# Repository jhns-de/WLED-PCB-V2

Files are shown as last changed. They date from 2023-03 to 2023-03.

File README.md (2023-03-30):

# WLED PCB V2

This is an ESP8266 based controller to drive addressable 12V [GS8208](www.normandled.com/upload/201805/GS8208%20LED%20Datasheet.pdf) LED Strips with the amazing [WLED](https://github.com/Aircoookie/WLED) firmware.

**This PCB was designed in [KiCad](https://www.kicad.org/).**

## Features

- Dimensions 95mm x 40mm
- Onboard LED for testing
- Fuse for overcurrent protection
- Reverse polarity protection for input and output
- [Recommended](https://kno.wled.ge/basics/compatible-hardware/#levelshifters) SN74AHCT125N Levelshifter
- Multiple decoupling capacitors
- IR receiver
- Relay for completely switching of the LED Stripe
- INA219 power sensor
- Multiple test points
- Onboard LED Stripe extension adapter

## Goal

This PCB was designed as an LED Stripe controller board for digital 12V GS8208 LED Strips built into a shelf. Therefore, it had to be easy to connect the LED Strips on either side of the board (depending if the board is mounted on the left or right side of the shelf). In addition, the LED Stripe hat to be easy extendable over the board, so the LED Stripe doesn't end before the shelf ends.

## More Information

Due to the backup line of the GS8208 LED design it is possible to completely remove the test led or the onboard led stripe extension adapter.

## Warning

In my first revision I connected the INA219 improperly. Therefore, I was unable to use it and never got to actually implementing the sensor into WLED. I updated the schematics and board to connect the INA219 sensor properly, but better check twice.

## WLED PCB V2

### Schematic

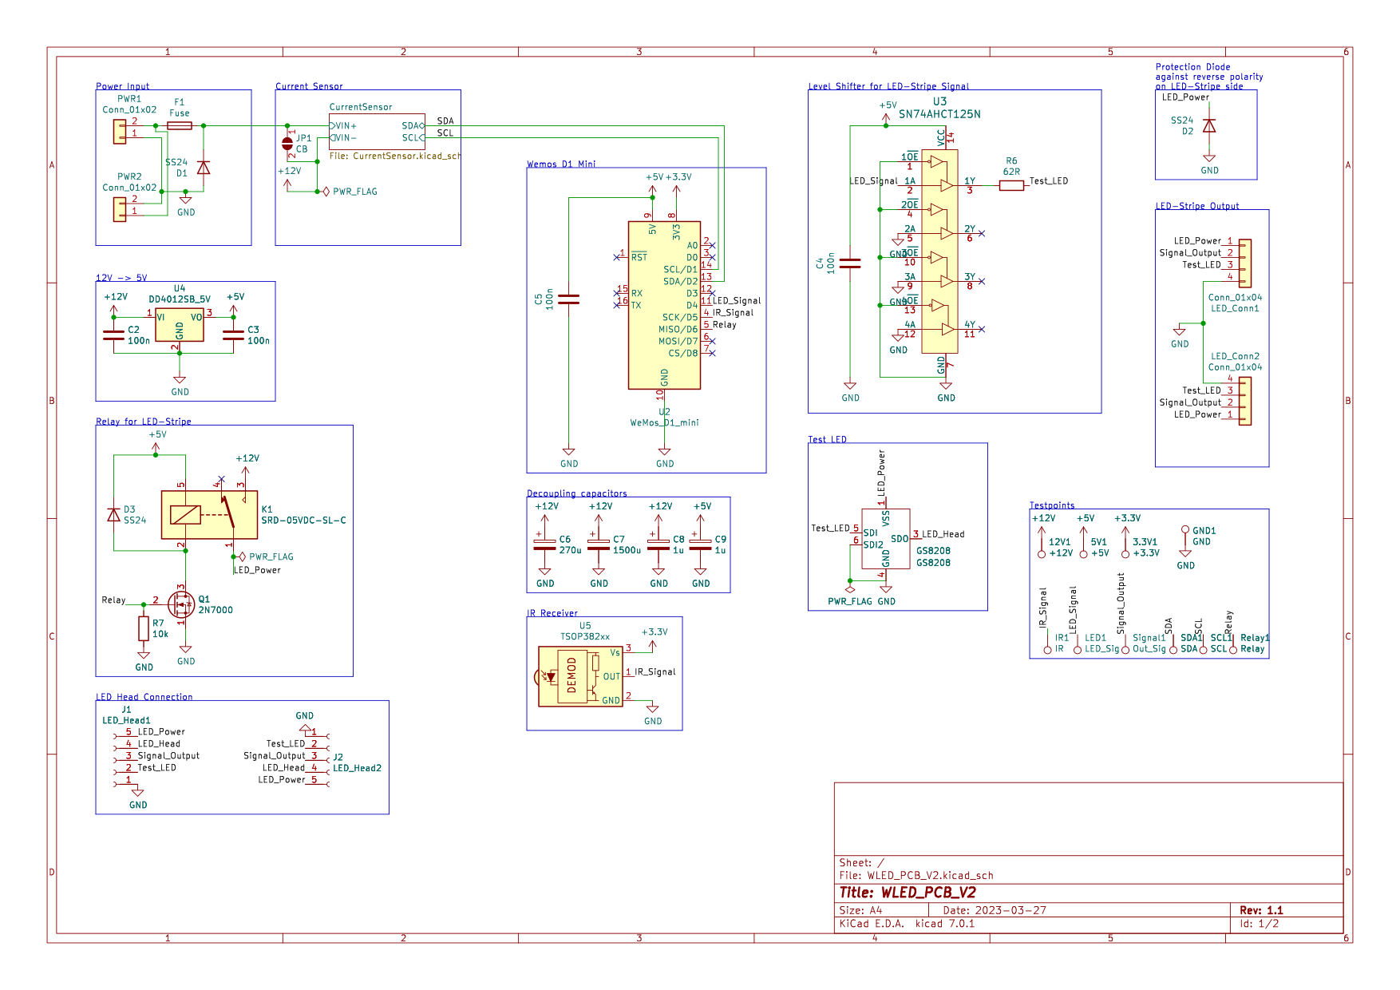
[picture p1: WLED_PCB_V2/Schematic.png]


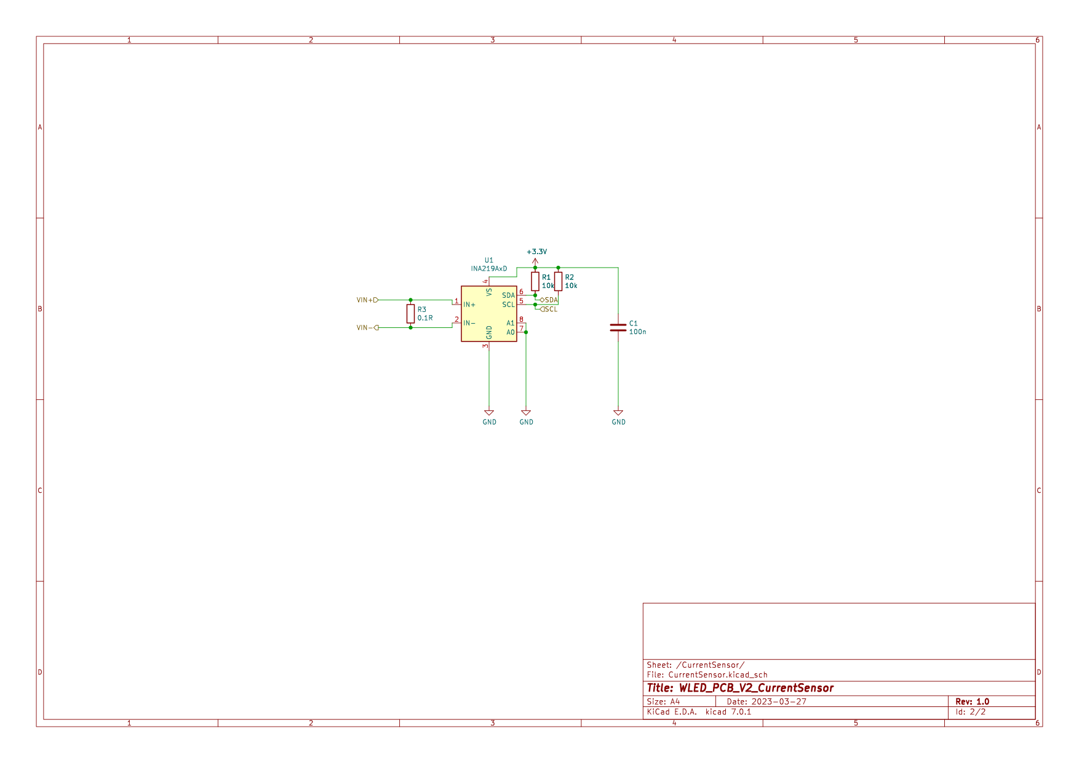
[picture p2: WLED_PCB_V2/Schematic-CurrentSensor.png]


### PCB

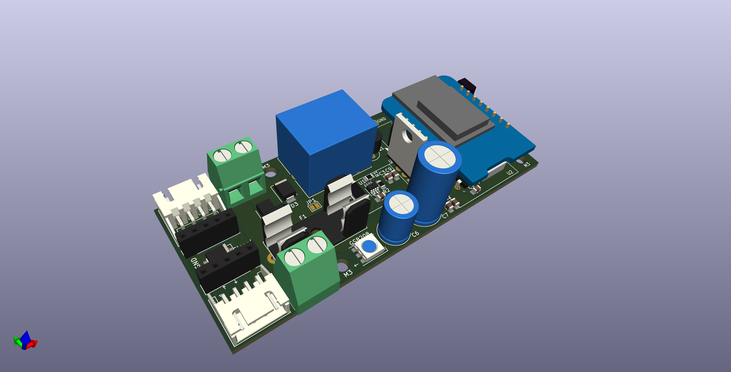
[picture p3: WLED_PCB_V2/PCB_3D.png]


#### Front

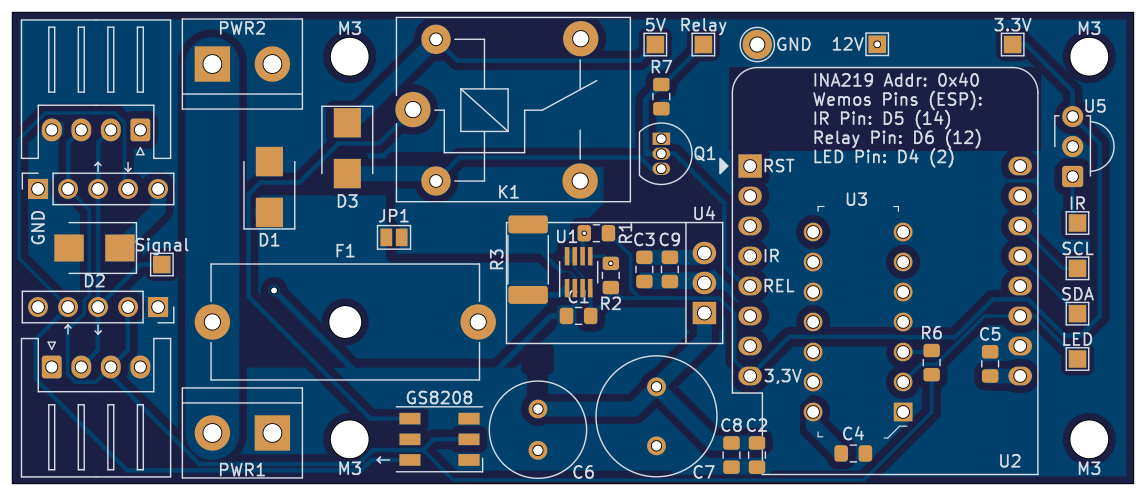
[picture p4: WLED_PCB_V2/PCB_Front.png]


#### Back

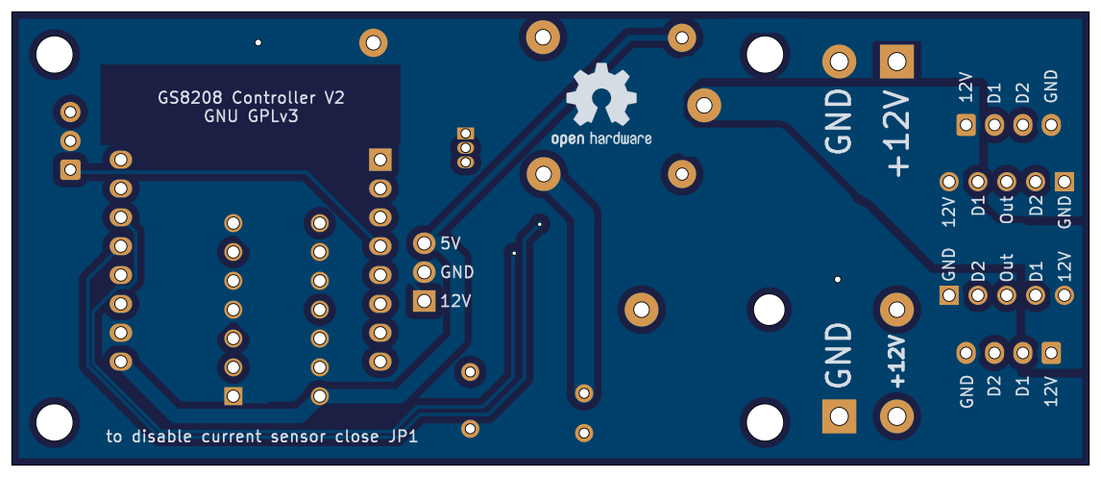
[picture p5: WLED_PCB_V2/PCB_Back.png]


## WLED PCB V2 LEDs

This is the onboard LED Stripe extension adapter, to extend the LED Stripe over the PCB board, so that the light ends at the end of the shelf. It contains 3 more GS8208 LEDs to extend the LED Stripe. By design it is possible to mount it in both directions, so it can be swapped if the controller is mounted on the other side of the shelf.

### Schematic

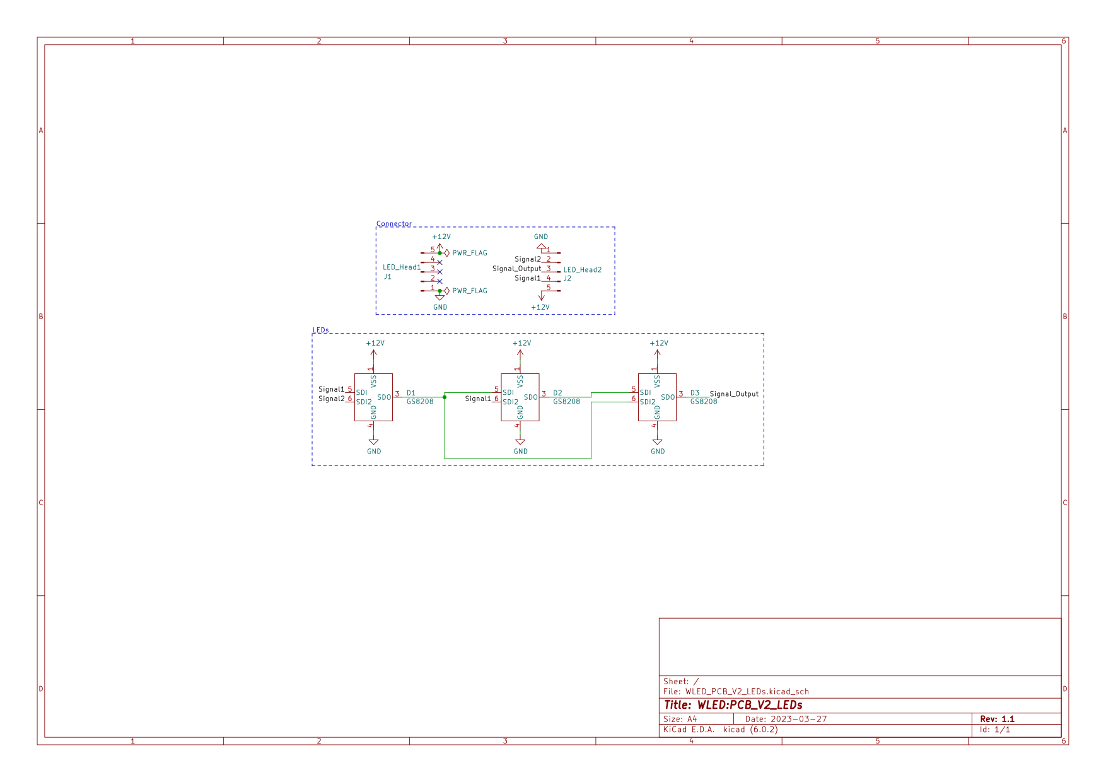
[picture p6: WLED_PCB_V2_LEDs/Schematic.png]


### PCB

The PCB is 14.25mm x 40.00mm.

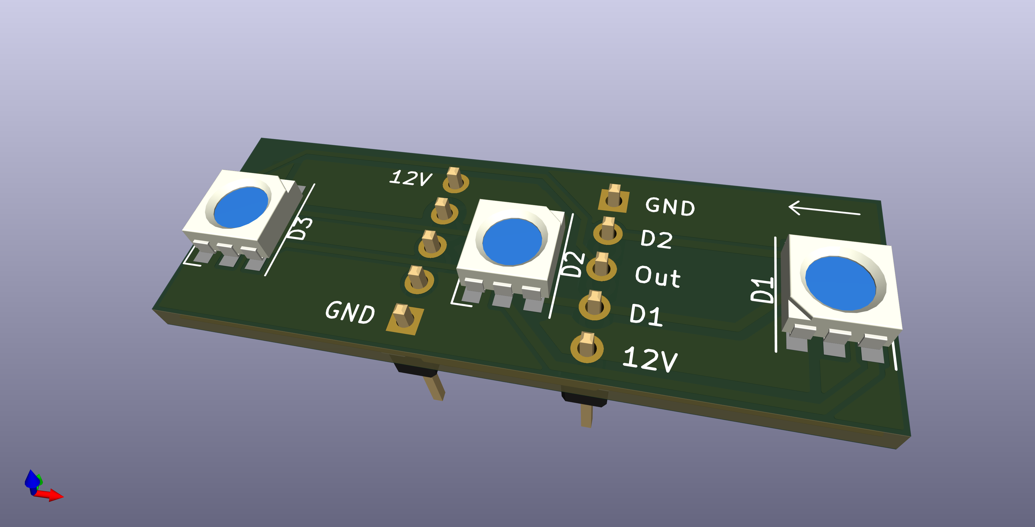
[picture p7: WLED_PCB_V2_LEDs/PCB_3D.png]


#### Front

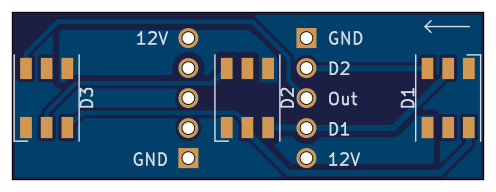
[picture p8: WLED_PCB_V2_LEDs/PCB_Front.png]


#### Back

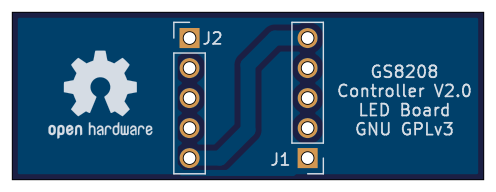
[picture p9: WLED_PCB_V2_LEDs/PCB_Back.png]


## Additional Information

### Photos

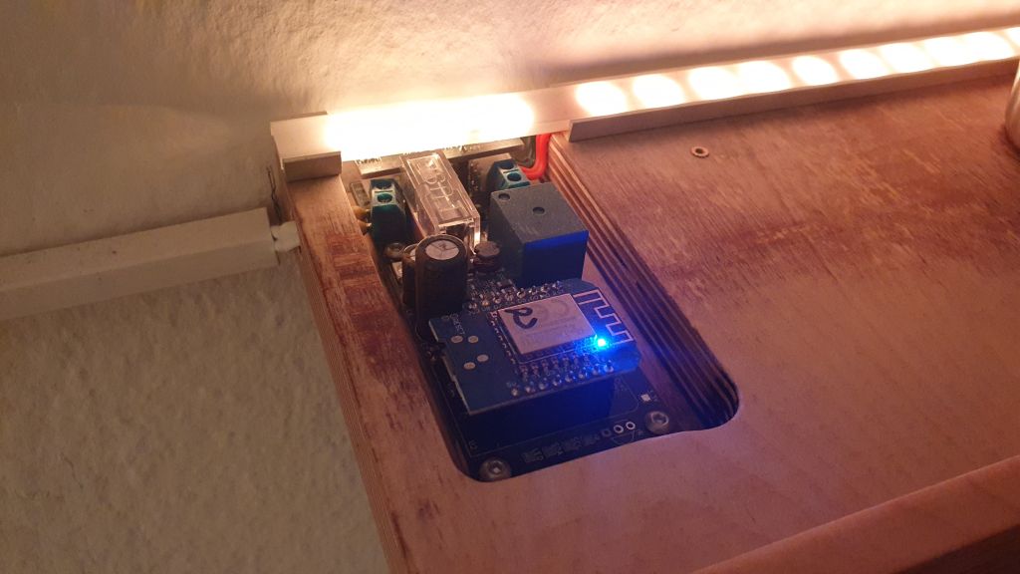
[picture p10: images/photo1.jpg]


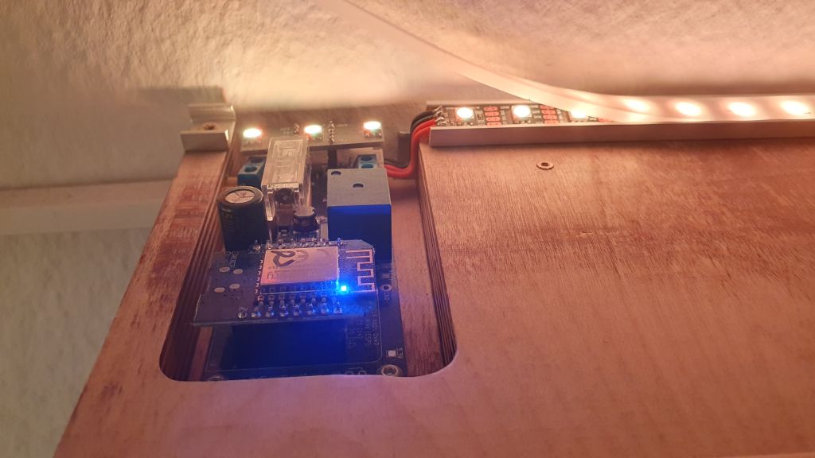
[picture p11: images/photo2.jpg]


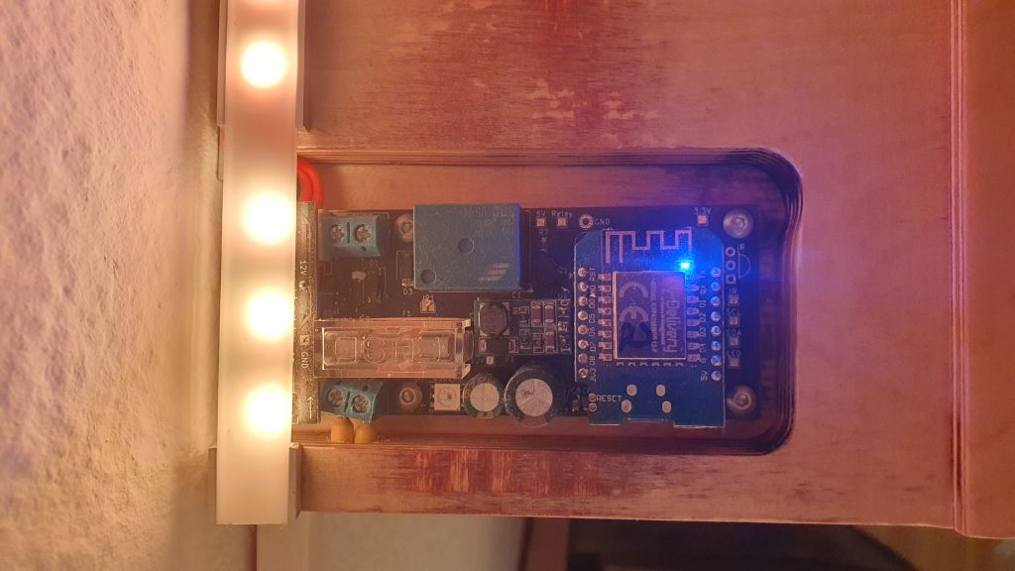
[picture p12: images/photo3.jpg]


### PcbDraw Command for PCB Images

[PcbDraw](https://github.com/yaqwsx/PcbDraw) is a tool for generating nice looking PCB images from KiCad files.

```
pcbdraw plot WLED_PCB_V2_LEDs.kicad_pcb PCB_Back.png --side back --style set-blue-cu --no-components
```

## License

This project is licensed under the GNU GPLv3.

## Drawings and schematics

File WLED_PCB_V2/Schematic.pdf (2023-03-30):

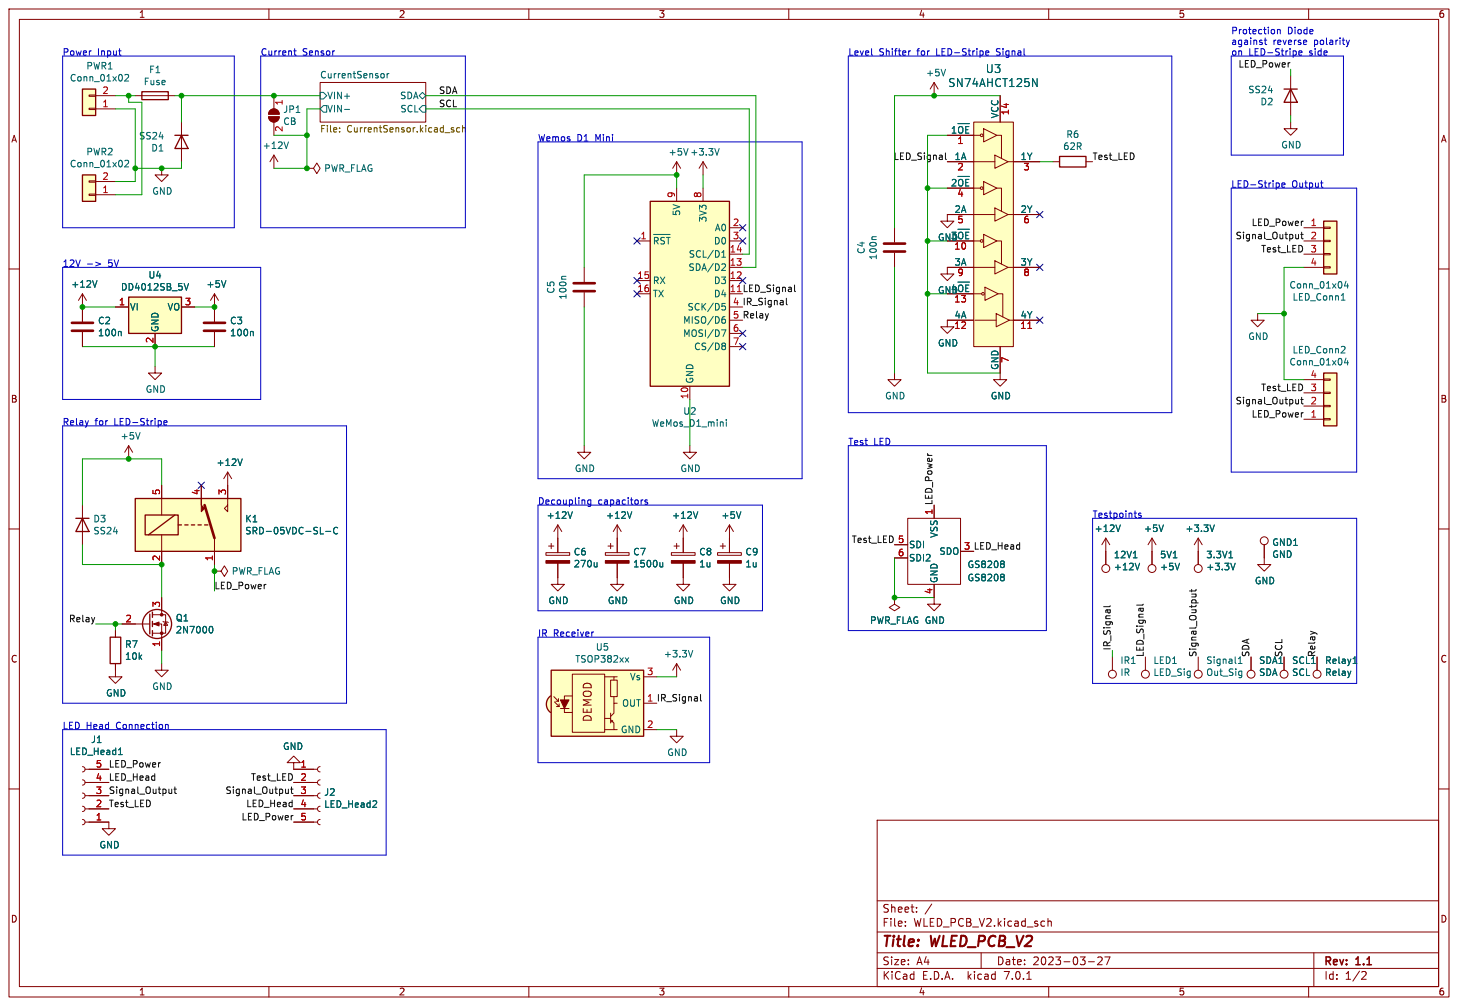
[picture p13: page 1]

1 2 JP1 CB GND GND GND

2 VO 3 U4 DD4012SB_5V GND GND +5V GND

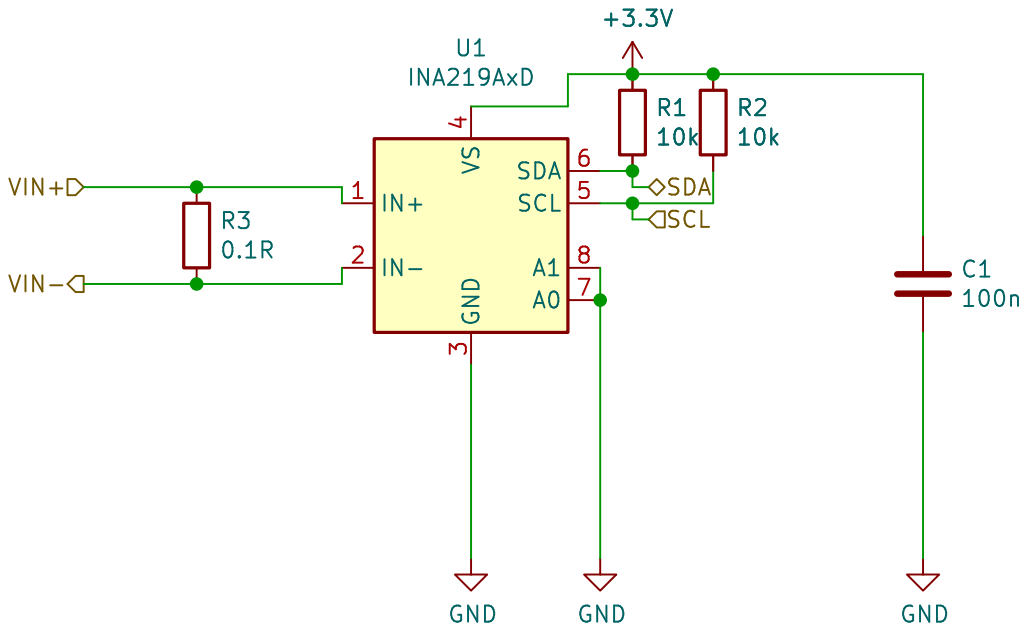
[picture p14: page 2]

Id: 2/2 Title: WLED_PCB_V2_CurrentSensor File: CurrentSensor.kicad_sch Sheet: /CurrentSensor/ GND

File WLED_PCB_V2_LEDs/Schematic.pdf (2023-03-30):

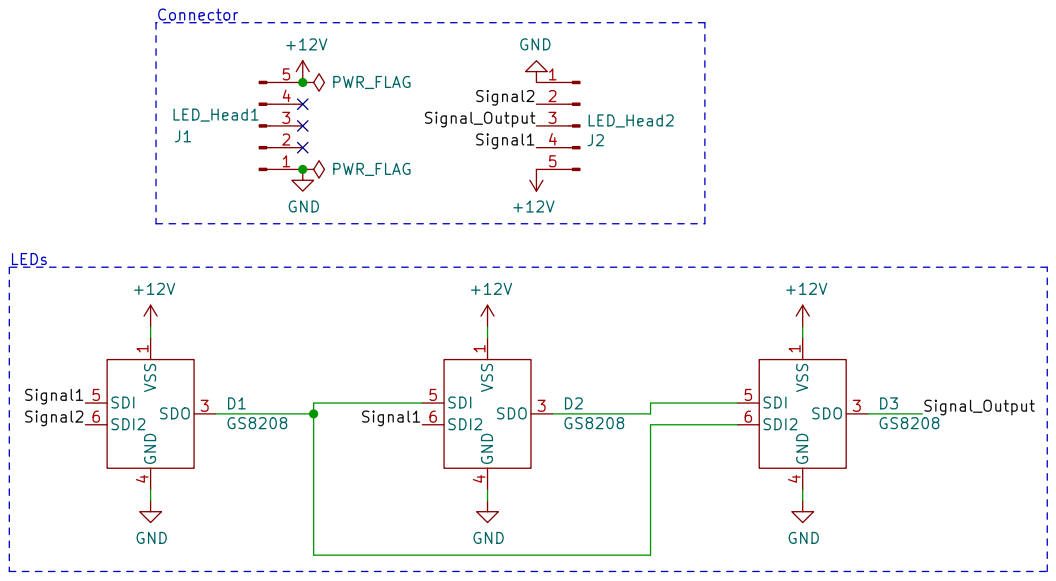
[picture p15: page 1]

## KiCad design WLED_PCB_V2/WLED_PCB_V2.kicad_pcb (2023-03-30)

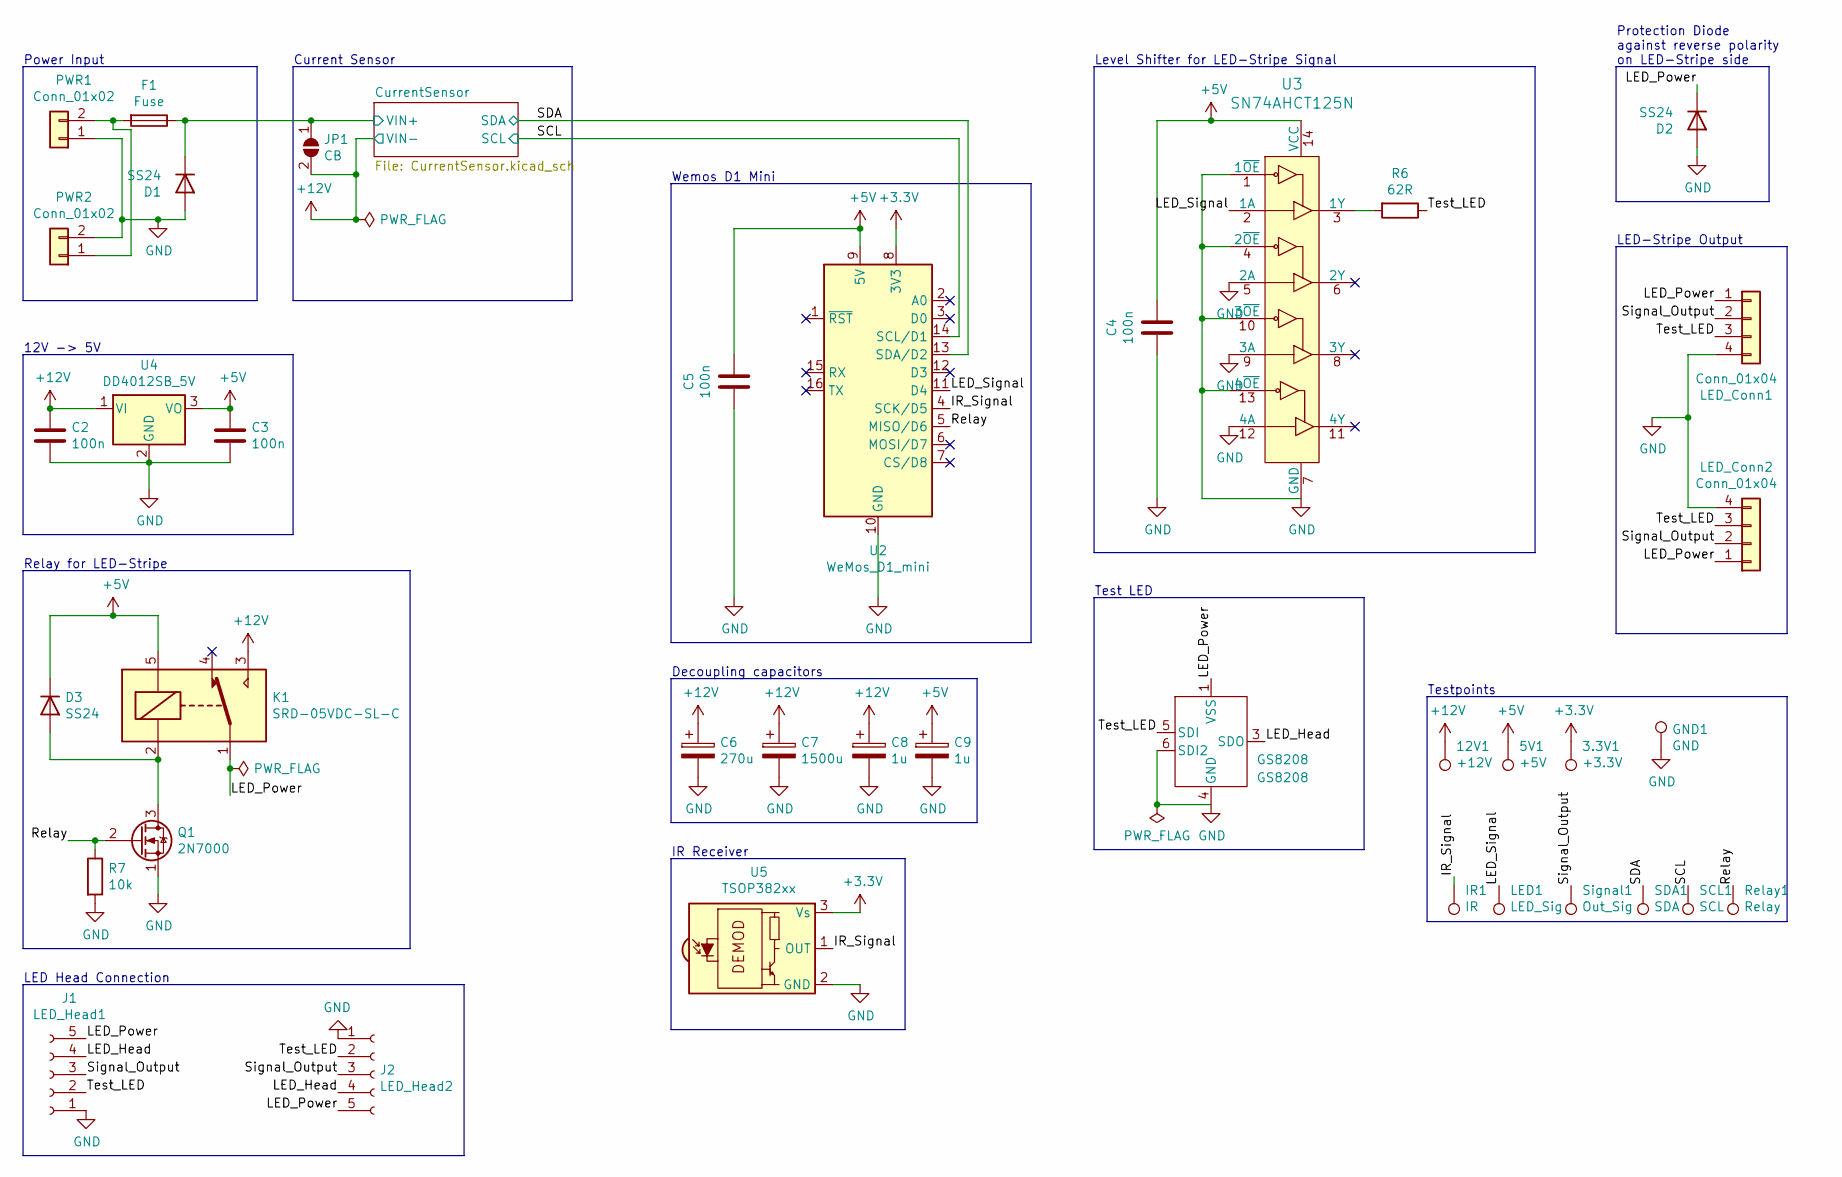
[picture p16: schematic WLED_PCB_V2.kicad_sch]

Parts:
3.3V1: +3.3V; TestPoint_Pad_1.5x1.5mm
5V1: +5V; TestPoint_Pad_1.5x1.5mm
12V1: +12V; TestPoint_Pad_1.5x1.5mm
C2, C3, C4, C5: 100n; C_0805_2012Metric_Pad1.15x1.40mm_HandSolder
C6: 270u; C_Radial_D8.0mm_H11.5mm_P3.50mm
C7: 1500u; C_Radial_D10.0mm_H20.0mm_P5.00mm
C8, C9: 1u; C_0805_2012Metric_Pad1.15x1.40mm_HandSolder
D1, D2, D3: SS24; D_SMB
F1: Fuse; Fuseholder_Cylinder-5x20mm_Schurter_0031_8201_Horizontal_Op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
GND1: GND; TestPoint_THTPad_D2.5mm_Drill1.2mm
GS8208: GS8208
IR1: IR; TestPoint_Pad_1.5x1.5mm
J1: LED_Head1; PinSocket_1x05_P2.54mm_Vertical
J2: LED_Head2; PinSocket_1x05_P2.54mm_Vertical
JP1: CB; SolderJumper-2_P1.3mm_Open_Pad1.0x1.5mm
K1: SRD-05VDC-SL-C; Relay_SPDT_SANYOU_SRD_Series_Form_C
LED1: LED_Sig; TestPoint_Pad_1.5x1.5mm
LED_Conn1, LED_Conn2: Conn_01x04; JST_XH_S4B-XH-A_1x04_P2.50mm_Horizontal
PWR1, PWR2: Conn_01x02; TerminalBlock_bornier-2_P5.08mm
Q1: 2N7000; TO-92_Inline
R6: 62R; R_0805_2012Metric_Pad1.15x1.40mm_HandSolder
R7: 10k; R_0805_2012Metric_Pad1.15x1.40mm_HandSolder
Relay1: Relay; TestPoint_Pad_1.5x1.5mm
SCL1: SCL; TestPoint_Pad_1.5x1.5mm
SDA1: SDA; TestPoint_Pad_1.5x1.5mm
Signal1: Out_Sig; TestPoint_Pad_1.5x1.5mm
U2: WeMos_D1_mini; WEMOS_D1_mini_light
U3: SN74AHCT125N; DIP-14_W3mm; MPN SN74AHCT125N; Digi-Key_PN 296-4655-5-ND
U4: DD4012SB_5V; DD4012S
U5: TSOP382xx; Vishay_MINICAST-3Pin

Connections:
+3V3: 3.3V1.1, U2.8 (3V3), U5.3 (Vs); also elsewhere on the board
+5V: 5V1.1, C3.1, C4.1, C5.1, C9.1, D3.1 (K), K1.5, U2.9 (5V), U3.14 (VCC), U4.3 (VO)
+12V: 12V1.1, C2.1, C6.1, C7.1, C8.1, JP1.2 (B), K1.3, U4.1 (VI); also elsewhere on the board
/CurrentSensor/VIN+: D1.1 (K), F1.1, JP1.1 (A); also elsewhere on the board
/IR_Signal: IR1.1, U2.4 (SCK/D5), U5.1 (OUT)
/LED_Head: GS8208.3 (SDO), J1.4, J2.4
/LED_Power: D2.1 (K), GS8208.1 (VSS), J1.5, J2.5, K1.1, LED_Conn1.1, LED_Conn2.1
/LED_Signal: LED1.1, U2.11 (D4), U3.2 (1A)
/Relay: Q1.2 (G), R7.1, Relay1.1, U2.5 (MISO/D6)
/SCL: SCL1.1, U2.14 (SCL/D1); also elsewhere on the board
/SDA: SDA1.1, U2.13 (SDA/D2); also elsewhere on the board
/Signal_Output: J1.3, J2.3, LED_Conn1.2, LED_Conn2.2, Signal1.1
/Test_LED: GS8208.5 (SDI), J1.2, J2.2, LED_Conn1.3, LED_Conn2.3, R6.1
GND: C2.2, C3.2, C4.2, C5.2, C6.2, C7.2, C8.2, C9.2, D1.2 (A), D2.2 (A), GND1.1, GS8208.4 (GND), GS8208.6 (SDI2), J1.1, J2.1, LED_Conn1.4, LED_Conn2.4, PWR1.1, PWR2.2, Q1.1 (S), R7.2, U2.10 (GND), U3.1 (1~OE), U3.4 (2~OE), U3.5 (2A), U3.7 (GND), U3.9 (3A), U3.10 (3~OE), U3.12 (4A), U3.13 (4~OE), U4.2 (GND), U5.2 (GND); also elsewhere on the board
unnamed: D3.2 (A), K1.2, Q1.3 (D)
unnamed: F1.2, PWR1.2, PWR2.1
unnamed: R6.2, U3.3 (1Y)

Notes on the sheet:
12V -> 5V
LED Head Connection
Relay for LED-Stripe
Current Sensor
Level Shifter for LED-Stripe Signal
Power Input
Test LED
IR Receiver
LED-Stripe Output
Testpoints
Protection Diode against reverse polarity on LED-Stripe side
Decoupling capacitors
Wemos D1 Mini

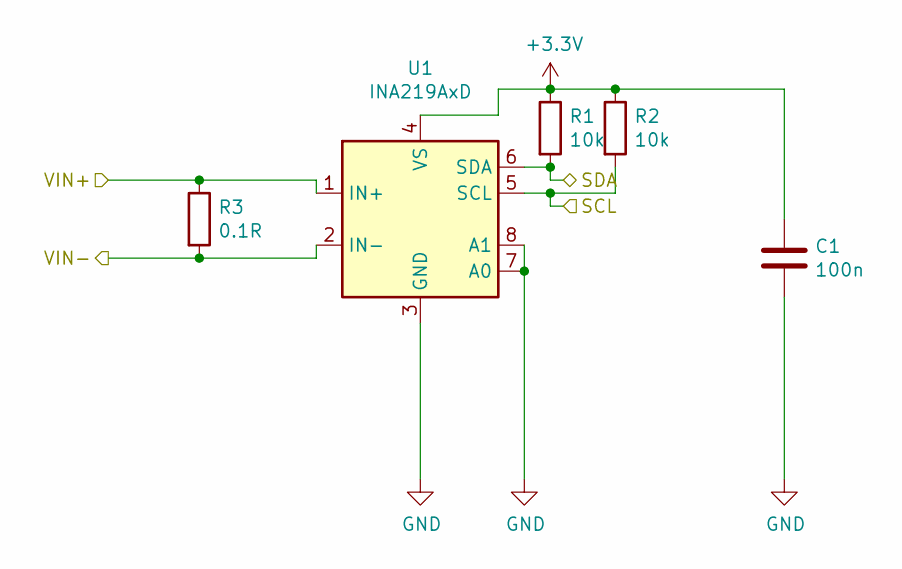
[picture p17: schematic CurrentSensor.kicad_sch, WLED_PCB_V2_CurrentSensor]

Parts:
C1: 100n; C_0805_2012Metric_Pad1.15x1.40mm_HandSolder
R1, R2: 10k; R_0805_2012Metric_Pad1.15x1.40mm_HandSolder
R3: 0.1R; R_2512_6332Metric_Pad1.52x3.35mm_HandSolder
U1: INA219AxD; SOT-23-8_Handsoldering

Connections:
+3V3: C1.1, R1.1, R2.1, U1.4 (VS); also elsewhere on the board
+12V: R3.2, U1.2 (IN-); also elsewhere on the board
/CurrentSensor/VIN+: R3.1, U1.1 (IN+); also elsewhere on the board
/SCL: R2.2, U1.5 (SCL); also elsewhere on the board
/SDA: R1.2, U1.6 (SDA); also elsewhere on the board
GND: C1.2, U1.3 (GND), U1.7 (A0), U1.8 (A1); also elsewhere on the board

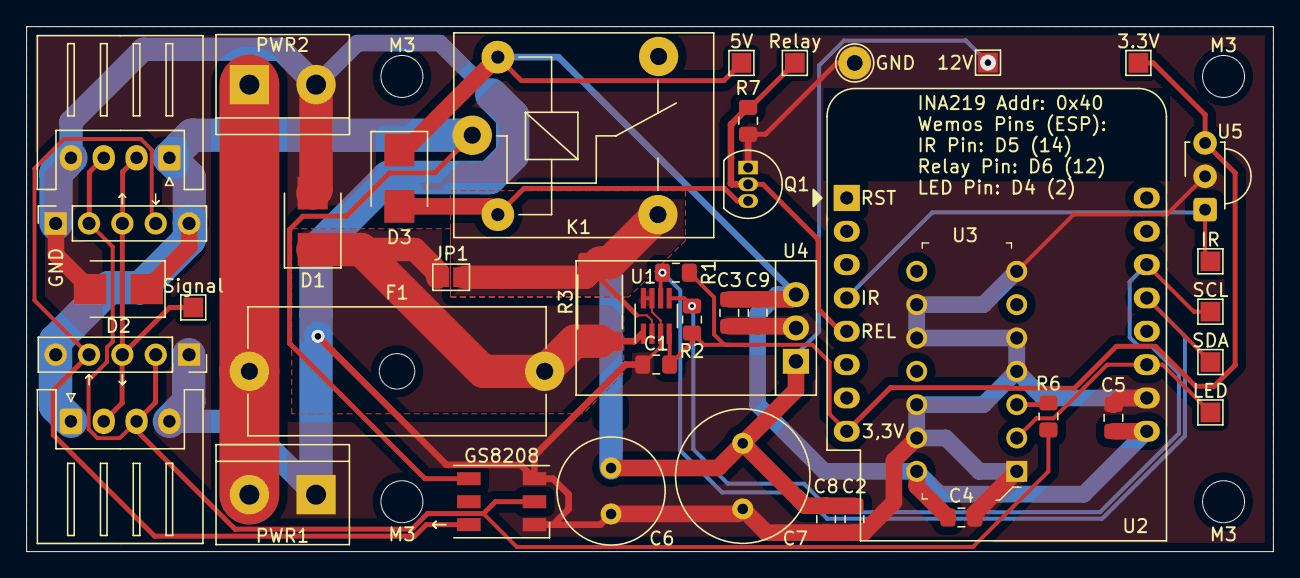
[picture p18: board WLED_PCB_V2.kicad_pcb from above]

Board: 2 copper layers, 95.0 x 40.0 mm, 43 parts (0 on the bottom side), 17 nets.

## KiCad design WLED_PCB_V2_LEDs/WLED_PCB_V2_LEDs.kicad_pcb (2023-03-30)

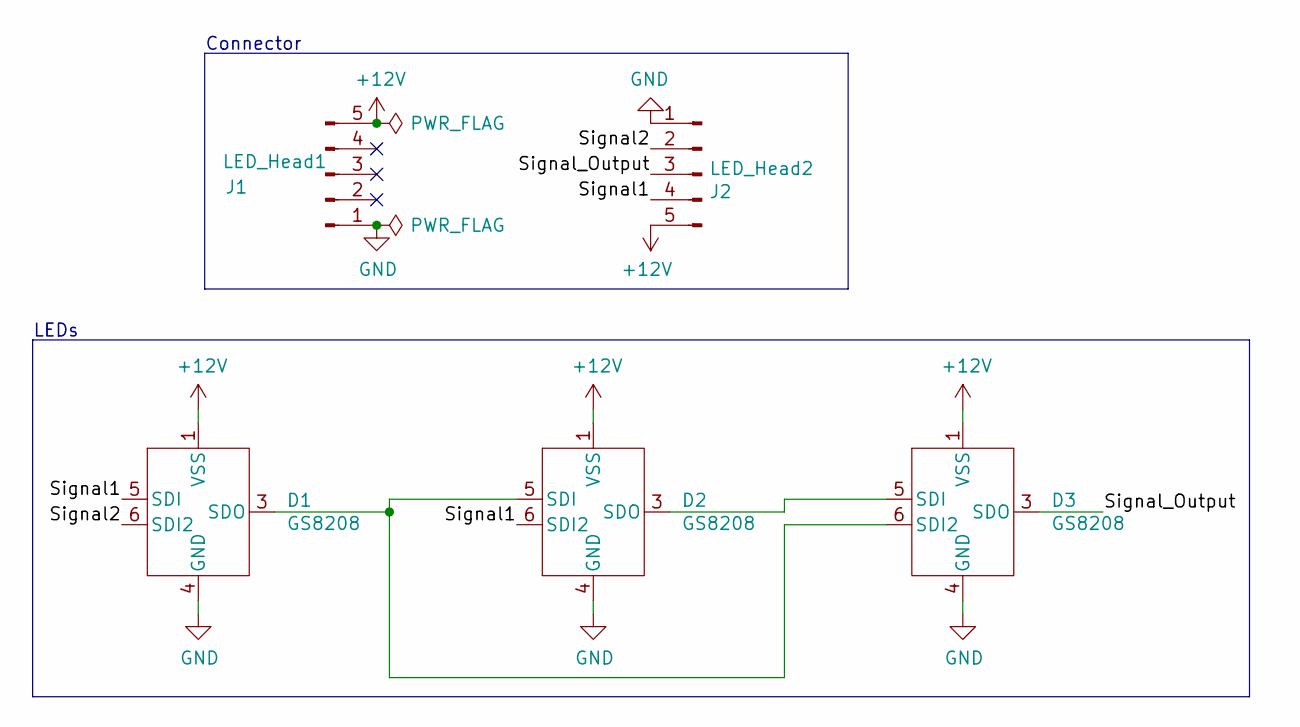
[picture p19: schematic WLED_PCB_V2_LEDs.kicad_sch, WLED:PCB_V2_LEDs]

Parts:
D1, D2, D3: GS8208
J1: LED_Head1; PinHeader_1x05_P2.54mm_Vertical
J2: LED_Head2; PinHeader_1x05_P2.54mm_Vertical

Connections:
+12V: D1.1 (VSS), D2.1 (VSS), D3.1 (VSS), J1.5, J2.5
/Signal1: D1.5 (SDI), D2.6 (SDI2), J2.4
/Signal2: D1.6 (SDI2), J2.2
/Signal_Output: D3.3 (SDO), J2.3
GND: D1.4 (GND), D2.4 (GND), D3.4 (GND), J1.1, J2.1
unnamed: D1.3 (SDO), D2.5 (SDI), D3.6 (SDI2)
unnamed: D2.3 (SDO), D3.5 (SDI)

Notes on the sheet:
Connector
LEDs

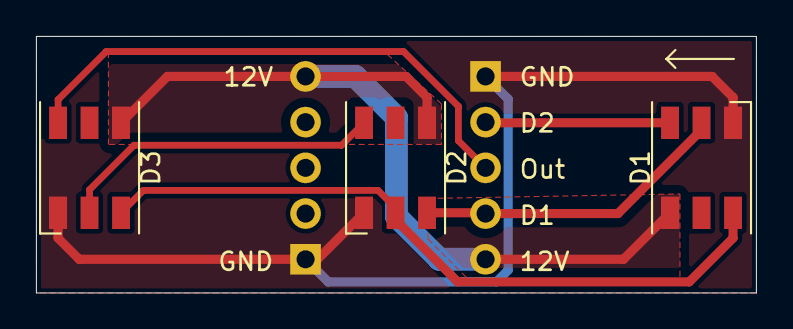
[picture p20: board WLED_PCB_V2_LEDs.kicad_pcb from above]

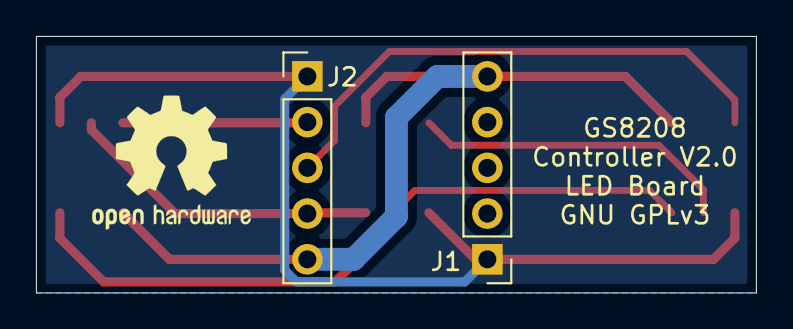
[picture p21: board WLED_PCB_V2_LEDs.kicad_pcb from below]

Board: 2 copper layers, 40.0 x 14.2 mm, 5 parts (2 on the bottom side), 7 nets.

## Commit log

2023-03-30 added custom symbols and PCBs
    [CurrentSensor.kicad_sch, WLED_PCB_V2.kicad_pcb, WLED_PCB_V2.kicad_sch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]
2023-03-30 added white background to schematics
